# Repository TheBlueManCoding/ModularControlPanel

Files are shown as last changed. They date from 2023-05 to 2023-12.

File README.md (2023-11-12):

# ModularControlPanel
Mechanics, PCB and Software for my modular control panel that is used with my cnc machine driven by LinuxCnc

If you need the mechanic parts, just open an issue and tell me.

This bboard delivers:
- 12 Key inputs
- 8 LED outputs driven by 2 boards of these: https://aliexpress.com/item/1005003772569293.html
- 3 ADC inputs
- directly routed inputs for connection to the control cabinet (connected via 15 Pin cable):
  - POWER_KEY or the standby Variant POWER_KEY_MAN, both enable POWER_EN 
  - START_KEY, STOP_KEY, BREAK_KEY
  - input for the ESTOP_LED
  - ESTOP connector
  - 3 Reserve lines
- I2C extension connectors for 3.3 and 5V I2C
- ws28 smart LED connector
- one connector for a MIST System (see https://github.com/TheBlueManCoding/WemosMosfet)

all switches are connected by:
- https://aliexpress.com/item/4000502453714.html
- https://aliexpress.com/item/1005001317075834.html

## Front view of the control panel mockup:
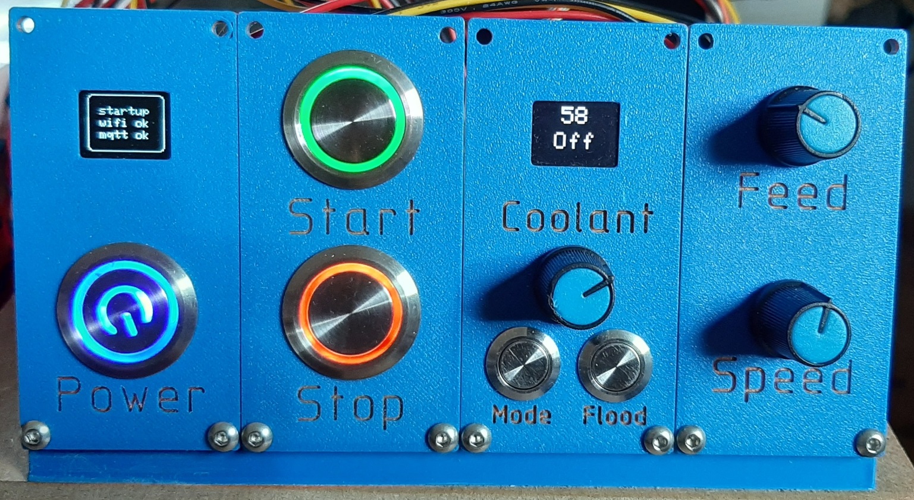
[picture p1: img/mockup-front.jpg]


#PCB with some connected switches, leds and the mist cooling controller
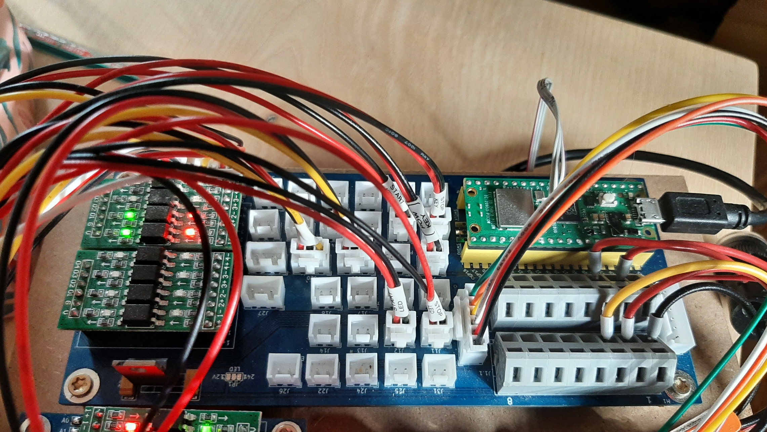
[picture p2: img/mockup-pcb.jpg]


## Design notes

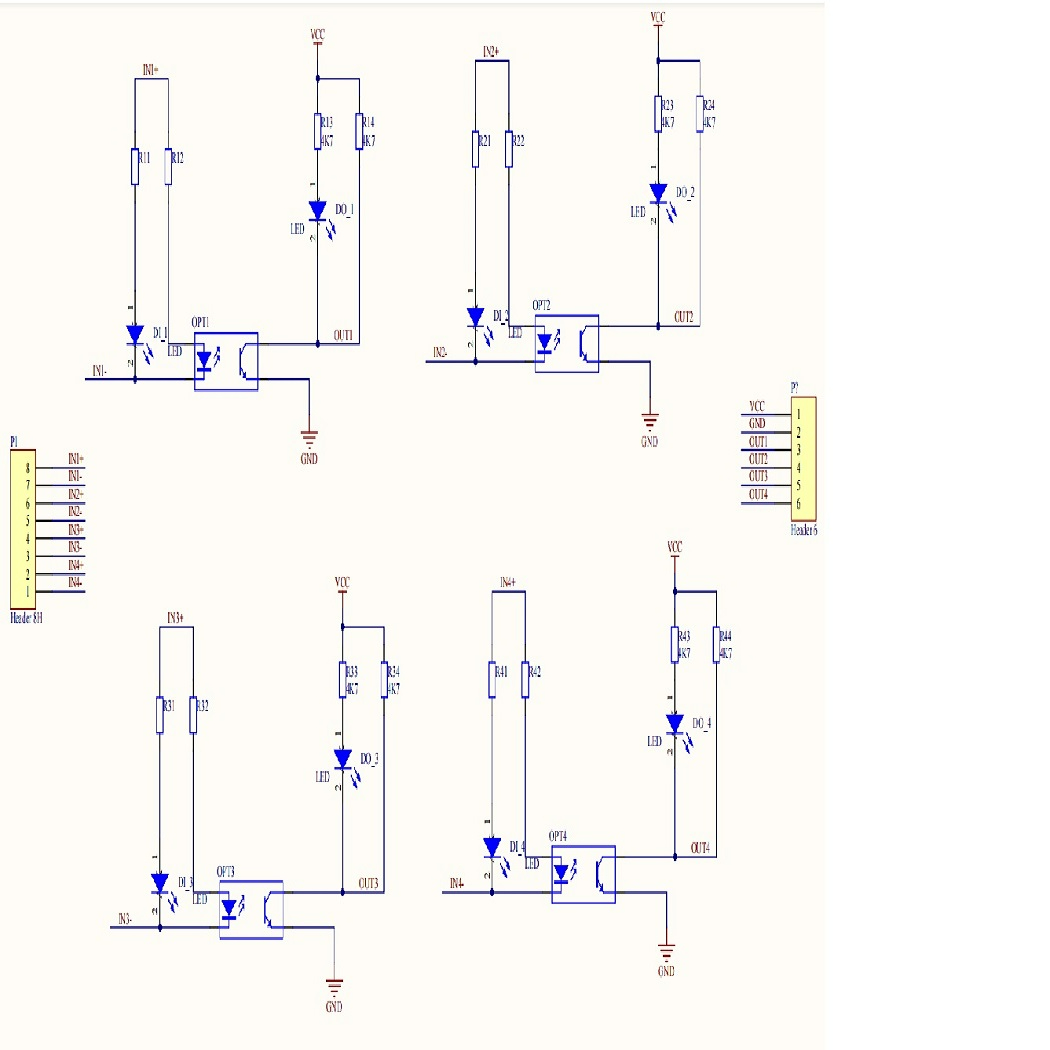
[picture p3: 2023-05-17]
pcb/OP71A04 Schematic.jpg

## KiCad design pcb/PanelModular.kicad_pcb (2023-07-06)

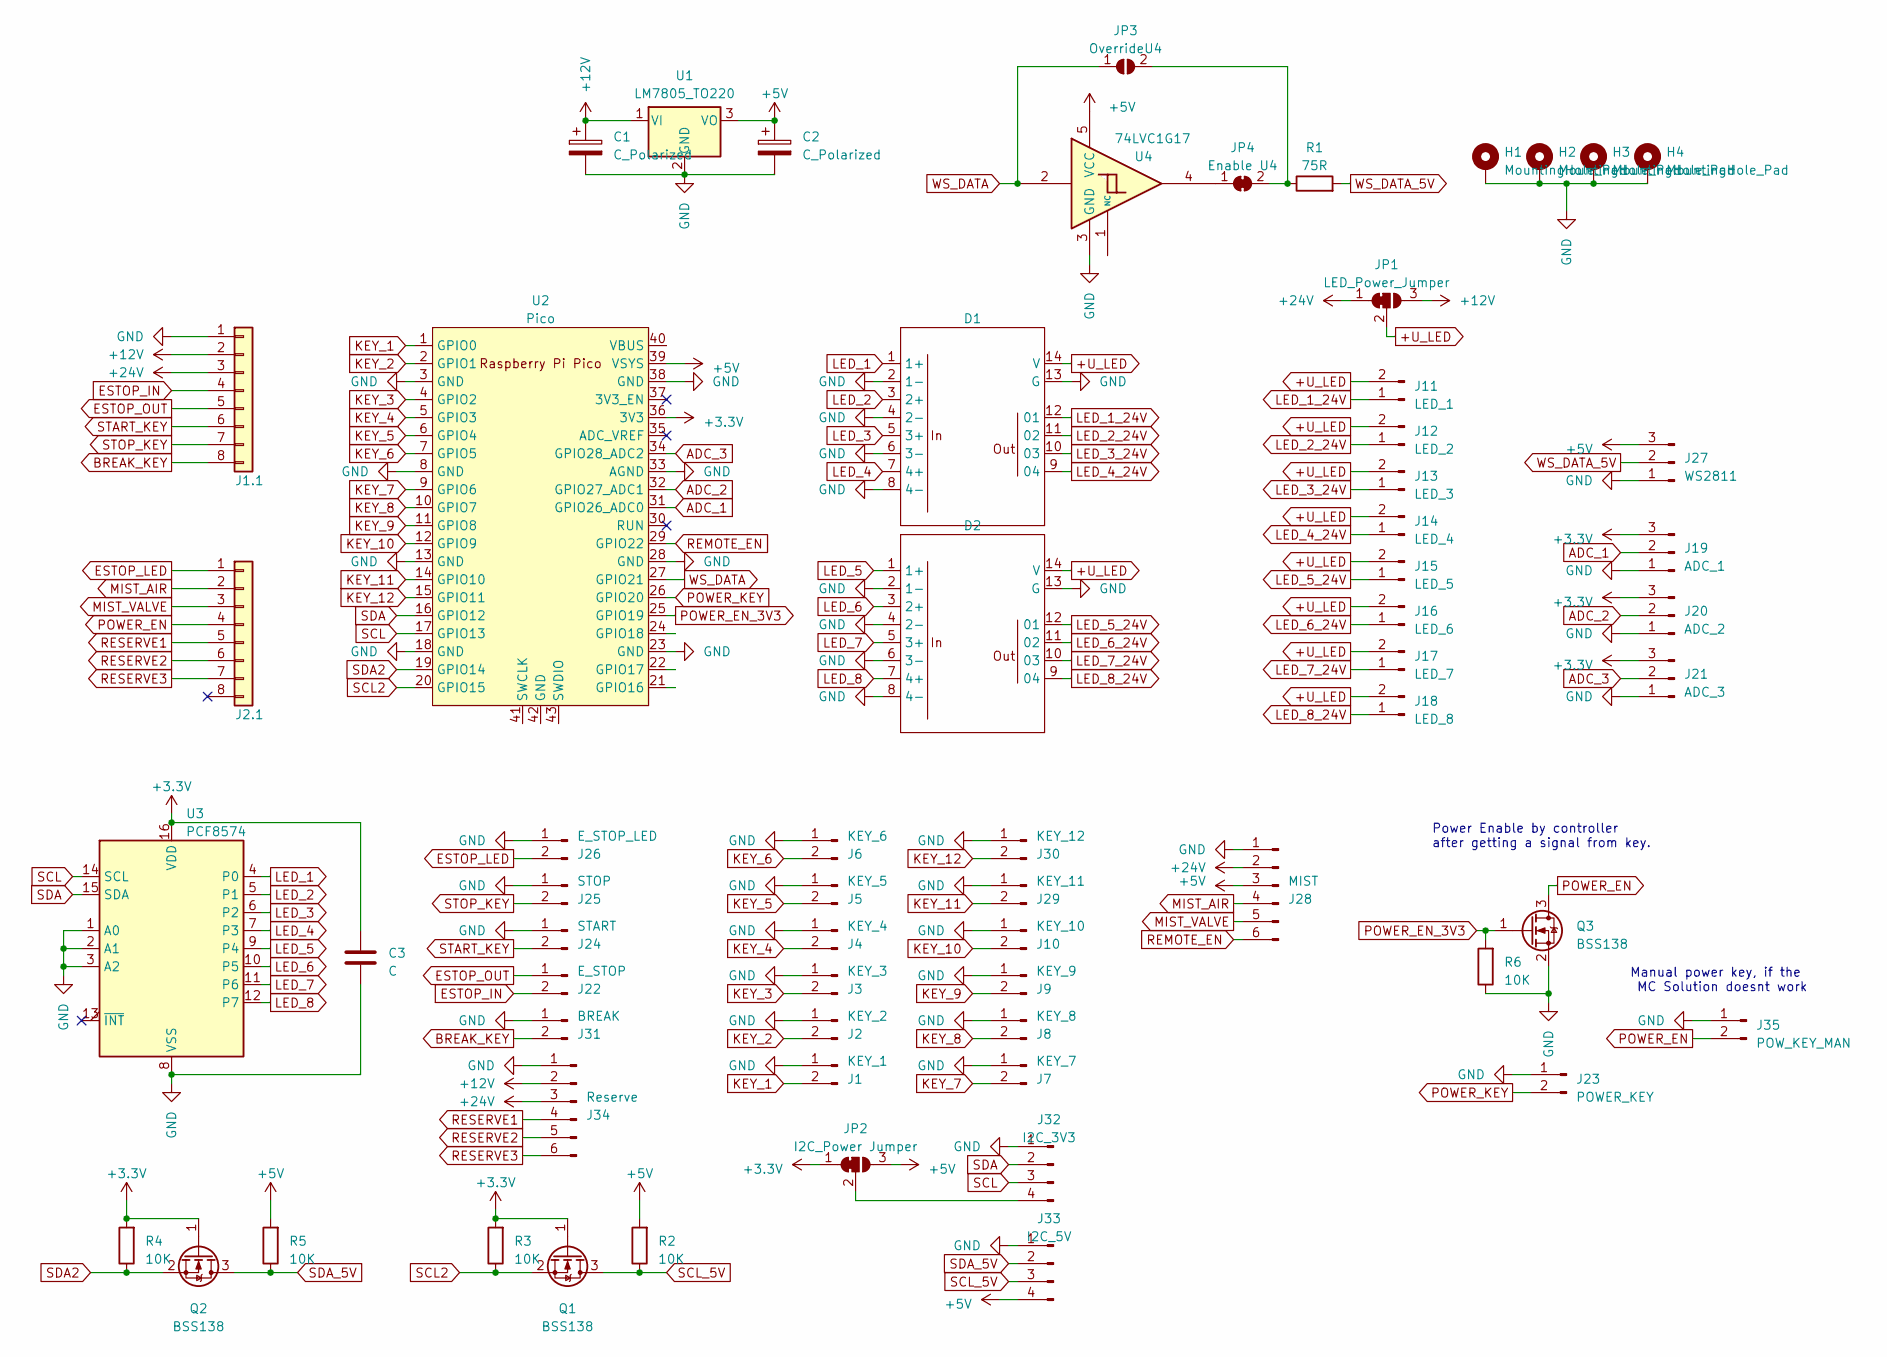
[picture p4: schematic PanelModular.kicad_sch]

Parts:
C1, C2: C_Polarized; CP_EIA-6032-28_Kemet-C_Pad2.25x2.35mm_HandSolder
C3: C; C_0805_2012Metric_Pad1.18x1.45mm_HandSolder
D1, D2: OP714A04
H1, H2, H3, H4: MountingHole_Pad; MountingHole_4.3mm_M4_Pad
J1: KEY_1; JST_XH_B2B-XH-A_1x02_P2.50mm_Vertical
J1.1, J2.1: Conn_01x08; TerminalBlock_WAGO_236-408_1x08_P5.00mm_45Degree
J2: KEY_2; JST_XH_B2B-XH-A_1x02_P2.50mm_Vertical
J3: KEY_3; JST_XH_B2B-XH-A_1x02_P2.50mm_Vertical
J4: KEY_4; JST_XH_B2B-XH-A_1x02_P2.50mm_Vertical
J5: KEY_5; JST_XH_B2B-XH-A_1x02_P2.50mm_Vertical
J6: KEY_6; JST_XH_B2B-XH-A_1x02_P2.50mm_Vertical
J7: KEY_7; JST_XH_B2B-XH-A_1x02_P2.50mm_Vertical
J8: KEY_8; JST_XH_B2B-XH-A_1x02_P2.50mm_Vertical
J9: KEY_9; JST_XH_B2B-XH-A_1x02_P2.50mm_Vertical
J10: KEY_10; JST_XH_B2B-XH-A_1x02_P2.50mm_Vertical
J11: LED_1; JST_XH_B2B-XH-A_1x02_P2.50mm_Vertical
J12: LED_2; JST_XH_B2B-XH-A_1x02_P2.50mm_Vertical
J13: LED_3; JST_XH_B2B-XH-A_1x02_P2.50mm_Vertical
J14: LED_4; JST_XH_B2B-XH-A_1x02_P2.50mm_Vertical
J15: LED_5; JST_XH_B2B-XH-A_1x02_P2.50mm_Vertical
J16: LED_6; JST_XH_B2B-XH-A_1x02_P2.50mm_Vertical
J17: LED_7; JST_XH_B2B-XH-A_1x02_P2.50mm_Vertical
J18: LED_8; JST_XH_B2B-XH-A_1x02_P2.50mm_Vertical
J19: ADC_1; JST_XH_B3B-XH-A_1x03_P2.50mm_Vertical
J20: ADC_2; JST_XH_B3B-XH-A_1x03_P2.50mm_Vertical
J21: ADC_3; JST_XH_B3B-XH-A_1x03_P2.50mm_Vertical
J22: E_STOP; JST_XH_B2B-XH-A_1x02_P2.50mm_Vertical
J23: POWER_KEY; JST_XH_B2B-XH-A_1x02_P2.50mm_Vertical
J24: START; JST_XH_B2B-XH-A_1x02_P2.50mm_Vertical
J25: STOP; JST_XH_B2B-XH-A_1x02_P2.50mm_Vertical
J26: E_STOP_LED; JST_XH_B2B-XH-A_1x02_P2.50mm_Vertical
J27: WS2811; JST_XH_B3B-XH-A_1x03_P2.50mm_Vertical
J28: MIST; JST_XH_B6B-XH-A_1x06_P2.50mm_Vertical
J29: KEY_11; JST_XH_B2B-XH-A_1x02_P2.50mm_Vertical
J30: KEY_12; JST_XH_B2B-XH-A_1x02_P2.50mm_Vertical
J31: BREAK; JST_XH_B2B-XH-A_1x02_P2.50mm_Vertical
J32: I2C_3V3; JST_XH_B4B-XH-A_1x04_P2.50mm_Vertical
J33: I2C_5V; JST_XH_B4B-XH-A_1x04_P2.50mm_Vertical
J34: Reserve; JST_XH_B6B-XH-A_1x06_P2.50mm_Vertical
J35: POW_KEY_MAN; JST_XH_B2B-XH-A_1x02_P2.50mm_Vertical
JP1: LED_Power_Jumper; SolderJumper-3_P1.3mm_Bridged12_Pad1.0x1.5mm_NumberLabels
JP2: I2C_Power Jumper; SolderJumper-3_P1.3mm_Bridged12_Pad1.0x1.5mm_NumberLabels
JP3: OverrideU4; SolderJumper-2_P1.3mm_Open_Pad1.0x1.5mm
JP4: Enable U4; SolderJumper-2_P1.3mm_Bridged_Pad1.0x1.5mm
Q1, Q2, Q3: BSS138; SOT-23_Handsoldering
R1: 75R; R_0805_2012Metric_Pad1.20x1.40mm_HandSolder
R2, R3, R4, R5, R6: 10K; R_0805_2012Metric_Pad1.20x1.40mm_HandSolder
U1: LM7805_TO220; TO-220-3_Vertical
U2: Pico; RPi_Pico_SMD_TH
U3: PCF8574; SO-16_7,7x10.2mm_P1.27mm-PCF8574
U4: 74LVC1G17; SOT-23-5_HandSoldering

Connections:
+3.3V: C3.1, J19.3, J20.3, J21.3, JP2.1 (A), Q1.1 (G), Q2.1 (G), R3.2, R4.2, U2.36 (3V3), U3.16 (VDD)
+5V: C2.1, J27.3, J28.3, J33.4, JP2.3 (B), R2.2, R5.2, U1.3 (VO), U2.39 (VSYS), U4.5 (VCC)
+12V: C1.1, J1.1.2, J34.2, JP1.3 (B), U1.1 (VI)
+24V: J1.1.3, J28.2, J34.3, JP1.1 (A)
+U_LED: D1.14 (V), D2.14 (V), J11.2, J12.2, J13.2, J14.2, J15.2, J16.2, J17.2, J18.2, JP1.2 (C)
ADC_1: J19.2, U2.31 (GPIO26_ADC0)
ADC_2: J20.2, U2.32 (GPIO27_ADC1)
ADC_3: J21.2, U2.34 (GPIO28_ADC2)
BREAK_KEY: J1.1.8, J31.2
ESTOP_IN: J1.1.4, J22.2
ESTOP_LED: J2.1.1, J26.2
ESTOP_OUT: J1.1.5, J22.1
GND: C1.2, C2.2, C3.2, D1.2 (1-), D1.4 (2-), D1.6 (3-), D1.8 (4-), D1.13 (G), D2.2 (1-), D2.4 (2-), D2.6 (3-), D2.8 (4-), D2.13 (G), H1.1, H2.1, H3.1, H4.1, J1.1, J1.1.1, J2.1, J3.1, J4.1, J5.1, J6.1, J7.1, J8.1, J9.1, J10.1, J19.1, J20.1, J21.1, J23.1, J24.1, J25.1, J26.1, J27.1, J28.1, J29.1, J30.1, J31.1, J32.1, J33.1, J34.1, J35.1, Q3.2 (S), R6.1, U1.2 (GND), U2.3 (GND), U2.8 (GND), U2.13 (GND), U2.18 (GND), U2.23 (GND), U2.28 (GND), U2.33 (AGND), U2.38 (GND), U3.1 (A0), U3.2 (A1), U3.3 (A2), U3.8 (VSS), U4.3 (GND)
KEY_1: J1.2, U2.1 (GPIO0)
KEY_2: J2.2, U2.2 (GPIO1)
KEY_3: J3.2, U2.4 (GPIO2)
KEY_4: J4.2, U2.5 (GPIO3)
KEY_5: J5.2, U2.6 (GPIO4)
KEY_6: J6.2, U2.7 (GPIO5)
KEY_7: J7.2, U2.9 (GPIO6)
KEY_8: J8.2, U2.10 (GPIO7)
KEY_9: J9.2, U2.11 (GPIO8)
KEY_10: J10.2, U2.12 (GPIO9)
KEY_11: J29.2, U2.14 (GPIO10)
KEY_12: J30.2, U2.15 (GPIO11)
LED_1: D1.1 (1+), U3.4 (P0)
LED_1_24V: D1.12 (01), J11.1
LED_2: D1.3 (2+), U3.5 (P1)
LED_2_24V: D1.11 (02), J12.1
LED_3: D1.5 (3+), U3.6 (P2)
LED_3_24V: D1.10 (03), J13.1
LED_4: D1.7 (4+), U3.7 (P3)
LED_4_24V: D1.9 (04), J14.1
LED_5: D2.1 (1+), U3.9 (P4)
LED_5_24V: D2.12 (01), J15.1
LED_6: D2.3 (2+), U3.10 (P5)
LED_6_24V: D2.11 (02), J16.1
LED_7: D2.5 (3+), U3.11 (P6)
LED_7_24V: D2.10 (03), J17.1
LED_8: D2.7 (4+), U3.12 (P7)
LED_8_24V: D2.9 (04), J18.1
MIST_AIR: J2.1.2, J28.4
MIST_VALVE: J2.1.3, J28.5
unnamed: J32.4, JP2.2 (C)
unnamed: JP3.2 (B), JP4.2 (B), R1.1
unnamed: JP4.1 (A), U4.4
POWER_EN: J2.1.4, J35.2, Q3.3 (D)
POWER_EN_3V3: Q3.1 (G), R6.2, U2.25 (GPIO19)
POWER_KEY: J23.2, U2.26 (GPIO20)
REMOTE_EN: J28.6, U2.29 (GPIO22)
RESERVE1: J2.1.5, J34.4
RESERVE2: J2.1.6, J34.5
RESERVE3: J2.1.7, J34.6
SCL: J32.3, U2.17 (GPIO13), U3.14 (SCL)
SCL2: Q1.2 (S), R3.1, U2.20 (GPIO15)
SCL_5V: J33.3, Q1.3 (D), R2.1
SDA: J32.2, U2.16 (GPIO12), U3.15 (SDA)
SDA2: Q2.2 (S), R4.1, U2.19 (GPIO14)
SDA_5V: J33.2, Q2.3 (D), R5.1
START_KEY: J1.1.6, J24.2
STOP_KEY: J1.1.7, J25.2
WS_DATA: JP3.1 (A), U2.27 (GPIO21), U4.2
WS_DATA_5V: J27.2, R1.2

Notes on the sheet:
Power Enable by controller after getting a signal from key.
Manual power key, if the MC Solution doesnt work

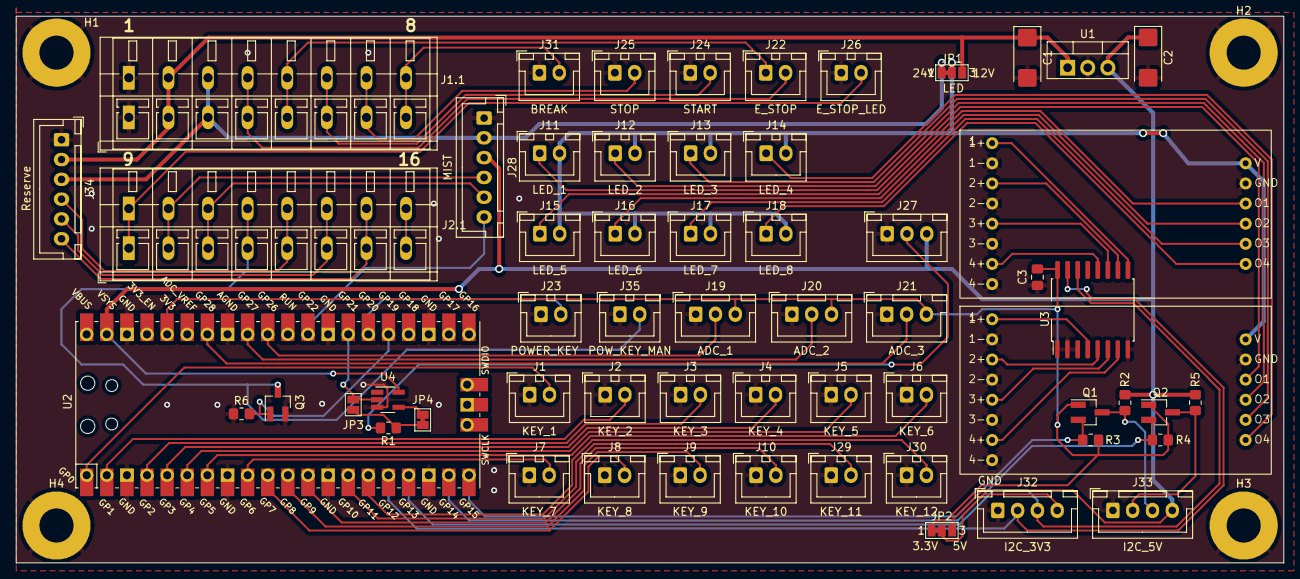
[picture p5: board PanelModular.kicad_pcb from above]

Board: 2 copper layers, 160.0 x 69.0 mm, 63 parts (0 on the bottom side), 63 nets.

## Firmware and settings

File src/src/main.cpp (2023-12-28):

#include <Arduino.h>

#include <Button.h>
#include <TCA9534.h>
#include <Wire.h>
#include <Adafruit_SSD1306.h>
#include <Mqtt.h>
#include <Inputs.h>
#include <Outputs.h>
#include <SecretSettings.h>

TCA9534 ioex;
PCF8574 ioex_extLED;
Adafruit_SSD1306 display(64, 48, &Wire, -1);

std::vector<InputButton*> inputs = {
  new InputButton(0, true),
  new InputButton(1, true),
  new InputButton(1, true),
  new InputButton(2, true),
  new InputButton(3, true),
  new InputButton(4, true),
  new InputButton(5, true),
  new InputButton(6, true),
  new InputButton(7, true),
  new InputButton(8, true),
  new InputButton(9, true),
  new InputButton(10, true),
  new InputButton(11, true)
};
InputAnalog inpa(1);

OutputGpio outMistRemoteEn(22, false);
OutputGpio outPowerEn3v3(19, false);

std::vector<AbstractDigitalOutput*> outputs = {
  new OutputTCA9534(&ioex, 0, false),
  new OutputTCA9534(&ioex, 1, false),
  new OutputTCA9534(&ioex, 2, false),
  new OutputTCA9534(&ioex, 3, false),
  new OutputTCA9534(&ioex, 4, false),
  new OutputTCA9534(&ioex, 5, false),
  new OutputTCA9534(&ioex, 6, false),
  new OutputTCA9534(&ioex, 6, false),
  new OutputPCF8574(&ioex_extLED, 0, true),
  new OutputPCF8574(&ioex_extLED, 1, true),
  new OutputPCF8574(&ioex_extLED, 2, true),
  new OutputPCF8574(&ioex_extLED, 3, true)
};

OutputMqtt outputDustCollector("shellies/staubsauger/relay/0/command", "toggle");
InputMqtt inputDustCollector("shellies/staubsauger/relay/0", "on", "off");
OutputMqtt outputCompressor("shellies/kompressor/relay/0/command", "toggle");
InputMqtt inputCompressor("shellies/kompressor/relay/0", "on", "off");
OutputMqtt outputBlower("shellies/lüfter/relay/0/command", "toggle");
InputMqtt inputBlower("shellies/lüfter/relay/0", "on", "off");

InputButton inputPowerKey(20, false);

class MqttObserver : public Mqtt::Observer {
  /// @brief called when the connection status has changed
  /// @param status the status
  void onConnectionStatusChange(ConnectionStatus status) override {
    display.clearDisplay();
    //display.drawRoundRect(0, 0, 64, 48, 4, SSD1306_WHITE);

    display.setCursor(5, 10);
    display.print("wifi ");
    if(status.wifiConnected) {
      display.println("  ok");
    } else {
      display.println("fail");
    }

    display.setCursor(5, 30);
    display.print("mqtt ");
    if(status.mqttConnected) {
      display.println("  ok");
    } else {
      display.println("fail");
    }

    display.display();
  }
}mqttObserver;

void setup() {
  Serial.begin(9600);

  Wire.setSDA(12);
  Wire.setSCL(13);
  Wire.begin();

  Wire1.setSDA(14);
  Wire1.setSCL(15);
  Wire1.begin();

  ioex.attach(Wire);
  ioex.setDeviceAddress(0x70 >> 1);
  ioex.output(0x00);

  ioex_extLED.attach(Wire1);
  ioex_extLED.setDeviceAddress(0x70 >> 1);
  ioex_extLED.output(0xFF);

  for(auto input : inputs) {
    input->begin();
  }

  for(auto output : outputs) {
    output->begin();
    output->write(1);
    delay(100);
  }

  for(auto output : outputs) {
    output->write(0);
    delay(100);
  }
  inputPowerKey.begin();
  inputDustCollector.begin();
  inputCompressor.begin();
  inputBlower.begin();

  outputDustCollector.begin();
  outputCompressor.begin();
  outputBlower.begin();

  inputPowerKey.connectOutput(outputs[8]);

  display.begin(SSD1306_SWITCHCAPVCC, 0x3C, false, false); // initialize with the I2C addr 0x3C (for the 64x48)
  display.clearDisplay();
  display.setTextColor(SSD1306_WHITE);
  display.display();

  Mqtt::setup(WIFI_SSID, WIFI_PASSWORD, MQTT_IP, MQTT_PORT, OWN_IP);
  Mqtt::instance()->setObserver(&mqttObserver);
  

  inputs[0]->connectOutput(&outputDustCollector);
  inputs[1]->connectOutput(&outputCompressor);
  inputDustCollector.connectOutput(outputs[0]);
  inputCompressor.connectOutput(outputs[1]);
}

void loop() {
  inputPowerKey.read();
  for(auto input : inputs) {
    input->read();
  }
  Mqtt::instance()->poll();
}

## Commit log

2023-05-17 First complete version of pcb
    [PanelModular.kicad_pcb, PanelModular.kicad_sch]
2023-05-22 I2C ready version
    [PanelModular.kicad_pcb, PanelModular.kicad_sch]
2023-07-05 The first ordered Version, missing i2c pullups and wrong i2c connected to external
    [PanelModular.kicad_pcb, PanelModular.kicad_sch]
2023-07-06 Revert "The first ordered Version, missing i2c pullups and wrong i2c connected to external"
    This reverts commit 4b4ee199a77fa0146eabba4f0e18928ce2f89e34.
    [PanelModular.kicad_pcb, PanelModular.kicad_sch]
2023-07-06 Really the first ordered Version, missing i2c pullups and wrong i2c connected to external
    [PanelModular.kicad_pcb, PanelModular.kicad_sch]
2023-07-18 All Hardware of PCB working
2023-11-12 Source files: - project update for cmsis-dap debugger (pico debugger) - Implemented input classes for digital and analog - digital inputs can toggle and directly connect to a digital output to connec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
    PCB users:
    - the PCF8574 i planned for the PCB doesn't workin my design as it can only sing. I use the TCA9534 which works fine.
    [main.cpp]
2023-12-28 Moved wifi credentials to: SecretSettings.h, build your own with SecretSettings.example.h
    Reworked Wifi/Mqtt stuff and packed into Mqtt.h
    Reworked Inputs:
    - New AbstractDigitalInput class that allows direct connection to outputs (e.g. you can connect the led directly to the button)
    Reworked outputs:
    - inverting the output now done in AbstractDigitalOutput
    main.cpp:
    - cleanup and set up of my configuration of the modularControlPanel
    - 8 onboard outputs
    - 4 additional i2c outputs for my addon board
    - 12 onboard inputs
    - some mqtt outputs with led's as mqtt input to show the actor status
